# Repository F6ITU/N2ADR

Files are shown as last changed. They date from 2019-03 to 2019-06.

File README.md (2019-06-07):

# N2ADR
N2ADR HPF &amp;  lpf for the Hermes Lite V2 project (fork heavily modified) 

This fork of the original N2ADR filter project (https://github.com/softerhardware/Hermes-Lite2/tree/master/hardware/companions/n2adr )
is designed on less expansive 2 sides only PCB. This filter can be directly plugged on a Hermes Lite V2 board or installed as a "piggy back" extension
fixed over the HL2 main board. This way, all input/output of the transmission system are located on the main frontplate of the transceiver. 

  - TR/PTT I/O is now using the same stereo jack used on the HL2 board
  - RX only SMA plug has been added
  - "Low power TX" and "RX only" RF path are routed thru coaxial jumpers to avoid impedance mismatch 
  - A heavy stitching of the board compensates the lack of insulation between RF traces and command bus

A specific pcb frontpanel is under development to accomodate this new configuration. 

Caveat emptor : 

This fork is a prototype. If you don't like risks, please built the original design

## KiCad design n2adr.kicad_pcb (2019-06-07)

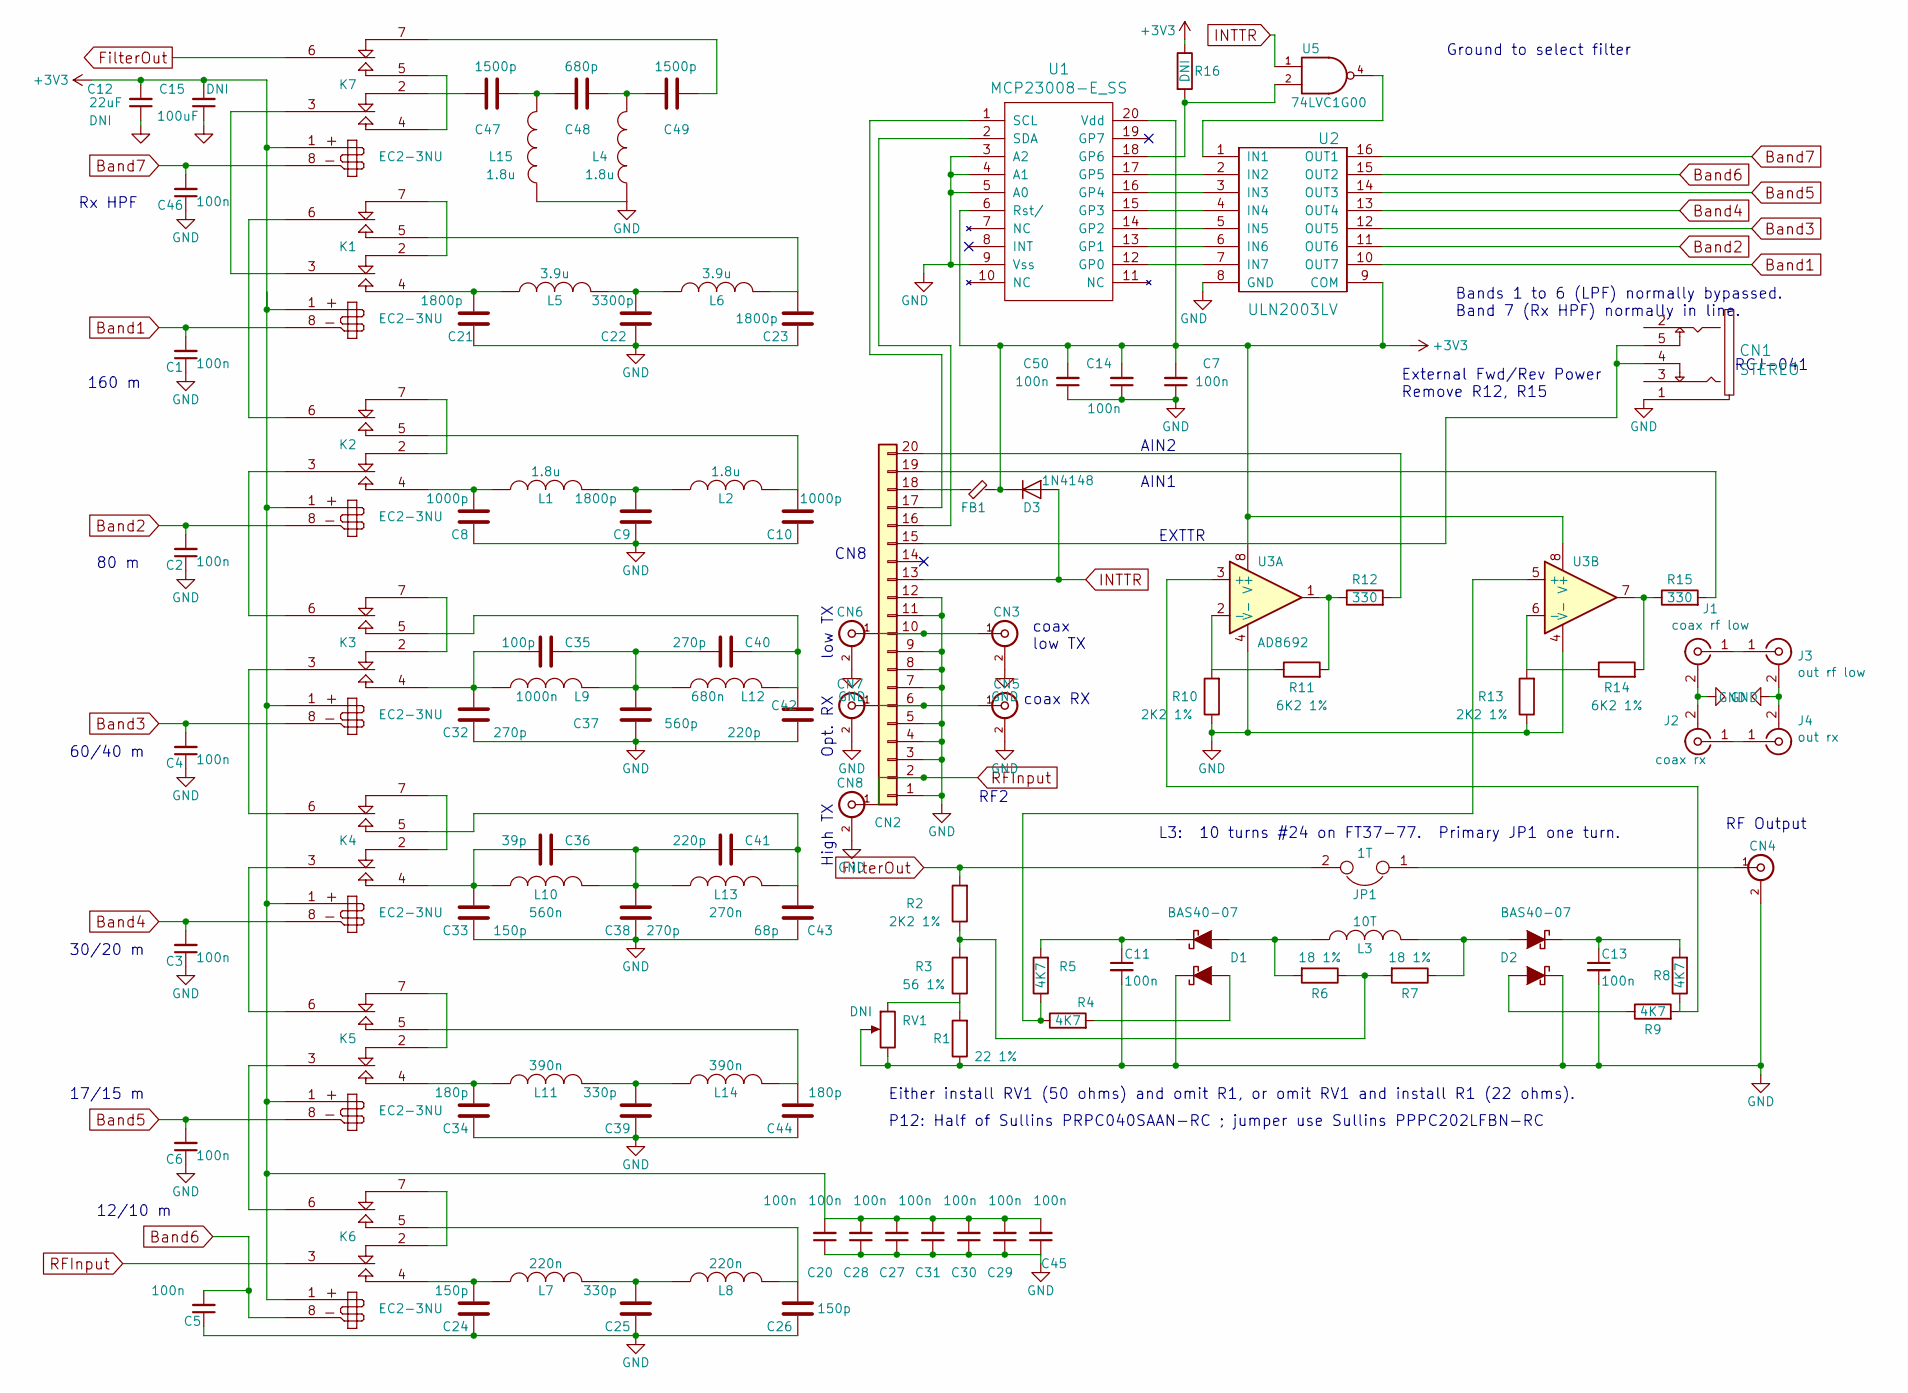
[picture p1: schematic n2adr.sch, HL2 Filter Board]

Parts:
C1, C2, C3, C4, C5, C6, C7, C11, C13, C14, C20, C27, C28, C29, C30, C31, C45, C46, C50: 100n; SMD_0805
C8, C10: 1000p; SMD_1206
C9, C21, C23: 1800p; SMD_1206
C12: 22uF; SMD_0805
C15: 100uF; SMD-1206
C22: 3300p; SMD_1206
C24, C26, C33: 150p; SMD_1206
C25, C39: 330p; SMD_1206
C32, C38, C40: 270p; SMD_1206
C34, C44: 180p; SMD_1206
C35: 100p; SMD_1206
C36: 39p; SMD_1206
C37: 560p; SMD_1206
C41, C42: 220p; SMD_1206
C43: 68p; SMD_1206
C47, C49: 1500p; SMD_0805
C48: 680p; SMD_0805
CN1: STEREO
CN2: Conn_01x20; Pin_Header_Straight_1x20_Pitch2.54mm
CN3: SMA; coax_2mm
CN4, CN6, CN7, CN8: SMA; SMA_EDGE_NRW
CN5: SMA; coax_1mm
D1, D2: BAS40-07; SOT-143
D3: 1N4148; D_SOD-123
FB1: FB; SMD_0805
J1: coax rf low; coax_2mm
J2: coax rx; coax_2mm
J3: out rf low; SMA_EDGE_NRW
J4: out rx; SMA_EDGE_NRW
JP1: 1T; WireConnection_1.20mmDrill
K1, K2, K3, K4, K5, K6, K7: EC2-3NU; RelayDPDT01
L1, L2: 1.8u; SMD_1812
L3: 10T; ToroidT37
L4, L15: 1.8u; SMD_0805
L5, L6: 3.9u; SMD_1812
L7, L8: 220n; SMD_1210
L9: 1000n; SMD_1812
L10: 560n; SMD_1210
L11, L14: 390n; SMD_1210
L12: 680n; SMD_1210
L13: 270n; SMD_1210
R1: 22 1%; SMD_0805
R2, R10, R13: 2K2 1%; SMD_0805
R3: 56 1%; SMD_0805
R4, R5, R8, R9: 4K7; SMD_0805
R6, R7: 18 1%; SMD_0805
R11, R14: 6K2 1%; SMD_0805
R12, R15: 330; SMD_0805
R16: DNI; SMD_0805
RV1: DNI; Trimpot_Bourns_3314G
U1: MCP23008-E_SS; SSOP-20_5.3x7.2mm_P0.65mm
U2: ULN2003LV; TSSOP-16_4.4x5mm_Pitch0.65mm
U3: AD8692; MSOP-8_3x3mm_Pitch0.65mm
U5: 74LVC1G00; SOT-23-5_HandSoldering

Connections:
+3V3: C7.2, C12.2, C14.2, C15.2, C20.2, C27.2, C28.2, C29.2, C30.2, C31.2, C45.2, C50.2, D3.1 (K), FB1.1, K1.1, K2.1, K3.1, K4.1, K5.1, K6.1, K7.1, R16.1, U1.6 (Rst/), U1.20 (Vdd), U2.9 (COM), U3.8 (V+), U5.5 (+3V3)
Band1: C1.2, K1.8, U2.10 (OUT7)
Band2: C2.2, K2.8, U2.11 (OUT6)
Band3: C4.2, K3.8, U2.12 (OUT5)
Band4: C3.2, K4.8, U2.13 (OUT4)
Band5: C6.2, K5.8, U2.14 (OUT3)
Band6: C5.2, K6.8, U2.15 (OUT2)
Band7: C46.2, K7.8, U2.16 (OUT1)
FilterOut: JP1.2, K7.6, R2.2
GND: C1.1, C2.1, C3.1, C4.1, C5.1, C6.1, C7.1, C8.1, C9.1, C10.1, C11.2, C12.1, C13.2, C14.1, C15.1, C20.1, C21.2, C22.2, C23.2, C24.1, C25.1, C26.1, C27.1, C28.1, C29.1, C30.1, C31.1, C32.1, C33.1, C34.1, C37.1, C38.1, C39.1, C42.1, C43.1, C44.1, C45.1, C46.1, C50.1, CN1.1, CN2.1, CN2.3, CN2.4, CN2.5, CN2.7, CN2.8, CN2.9, CN2.11, CN2.12, CN3.2 (Ext), CN4.2 (Ext), CN5.2 (Ext), CN6.2 (Ext), CN7.2 (Ext), CN8.2 (Ext), D1.1 (K), D2.2 (K), J1.2 (Ext), J2.2 (Ext), J3.2 (Ext), J4.2 (Ext), L4.1, L15.1, R1.1, R10.1, R13.1, RV1.2, RV1.3, U1.3 (A2), U1.4 (A1), U1.5 (A0), U1.9 (Vss), U2.8 (GND), U3.4 (V-), U5.3 (GND)
INTTR: CN2.13, D3.2 (A), U5.1
unnamed: C8.2, K2.4, L1.1
unnamed: C9.2, L1.2, L2.1
unnamed: C10.2, K2.5, L2.2
unnamed: C11.1, D1.2 (K), R5.2
unnamed: C13.1, D2.1 (K), R8.2
unnamed: C21.1, K1.4, L5.1
unnamed: C22.1, L5.2, L6.1
unnamed: C23.1, K1.5, L6.2
unnamed: C24.2, K6.4, L7.1
unnamed: C25.2, L7.2, L8.1
unnamed: C26.2, K6.5, L8.2
unnamed: C32.2, C35.2, K3.4, L9.1
unnamed: C33.2, C36.2, K4.4, L10.1
unnamed: C34.2, K5.4, L11.1
unnamed: C35.1, C37.2, C40.2, L9.2, L12.1
unnamed: C36.1, C38.2, C41.2, L10.2, L13.1
unnamed: C39.2, L11.2, L14.1
unnamed: C40.1, C42.2, K3.5, L12.2
unnamed: C41.1, C43.2, K4.5, L13.2
unnamed: C44.2, K5.5, L14.2
unnamed: C47.1, C48.2, L15.2
unnamed: C47.2, K7.2
unnamed: C48.1, C49.2, L4.2
unnamed: C49.1, K7.7
unnamed: CN1.4, CN1.5, CN2.15
unnamed: CN2.6, CN5.1 (In), CN7.1 (In)
unnamed: CN2.10, CN3.1 (In), CN6.1 (In)
unnamed: CN2.16, U1.2 (SDA)
unnamed: CN2.17, U1.1 (SCL)
unnamed: CN2.18, FB1.2
unnamed: CN2.19, R15.2
unnamed: CN2.20, R12.2
unnamed: CN4.1 (In), JP1.1
unnamed: D1.3 (A), L3.1, R6.2
unnamed: D1.4 (A), R4.2
unnamed: D2.3 (A), R9.1
unnamed: D2.4 (A), L3.2, R7.1
unnamed: J1.1 (In), J3.1 (In)
unnamed: J2.1 (In), J4.1 (In)
unnamed: K1.2, K1.7
unnamed: K1.3, K7.3
unnamed: K1.6, K2.6
unnamed: K2.2, K2.7
unnamed: K2.3, K3.6
unnamed: K3.2, K3.7
unnamed: K3.3, K4.6
unnamed: K4.2, K4.7
unnamed: K4.3, K5.6
unnamed: K5.2, K5.7
unnamed: K5.3, K6.6
unnamed: K6.2, K6.7
unnamed: K7.4, K7.5
unnamed: R1.2, R3.1, RV1.1
unnamed: R2.1, R3.2, R6.1, R7.2
unnamed: R4.1, R5.1, U3.5 (+)
unnamed: R8.1, R9.2, U3.3 (+)
unnamed: R10.2, R11.1, U3.2 (-)
unnamed: R11.2, R12.1, U3.1
unnamed: R13.2, R14.1, U3.6 (-)
unnamed: R14.2, R15.1, U3.7
unnamed: R16.2, U1.18 (GP6), U5.2
unnamed: U1.12 (GP0), U2.7 (IN7)
unnamed: U1.13 (GP1), U2.6 (IN6)
unnamed: U1.14 (GP2), U2.5 (IN5)
unnamed: U1.15 (GP3), U2.4 (IN4)
unnamed: U1.16 (GP4), U2.3 (IN3)
unnamed: U1.17 (GP5), U2.2 (IN2)
unnamed: U2.1 (IN1), U5.4
RFInput: CN2.2, CN8.1 (In), K6.3

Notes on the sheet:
Ground to select filter
RF Output
L3: 10 turns #24 on FT37-77. Primary JP1 one turn.
80 m
60/40 m
30/20 m
17/15 m
12/10 m
160 m
RF2
EXTTR
AIN2
AIN1
CN8
Opt. RX
External Fwd/Rev Power Remove R12, R15
RCJ-041
P12: Half of Sullins PRPC040SAAN-RC ; jumper use Sullins PPPC202LFBN-RC
Either install RV1 (50 ohms) and omit R1, or omit RV1 and install R1 (22 ohms).
Rx HPF
Bands 1 to 6 (LPF) normally bypassed. Band 7 (Rx HPF) normally in line.
coax low TX
coax RX
low TX
High TX

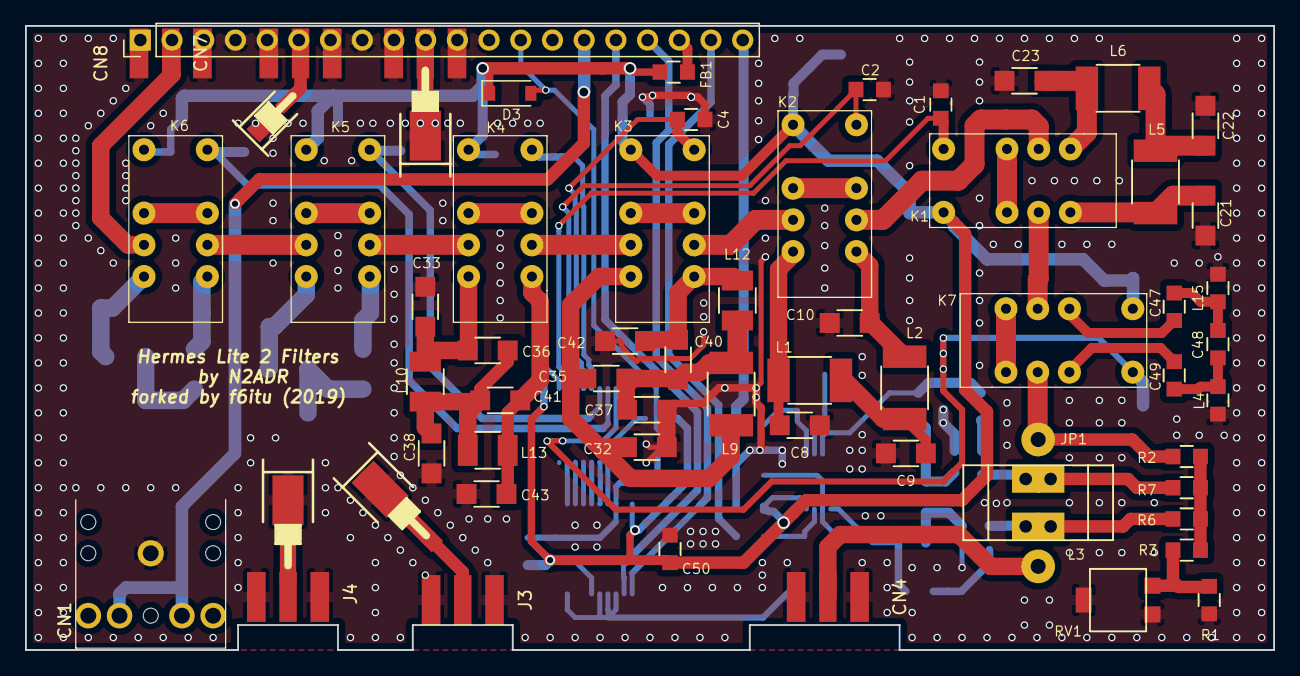
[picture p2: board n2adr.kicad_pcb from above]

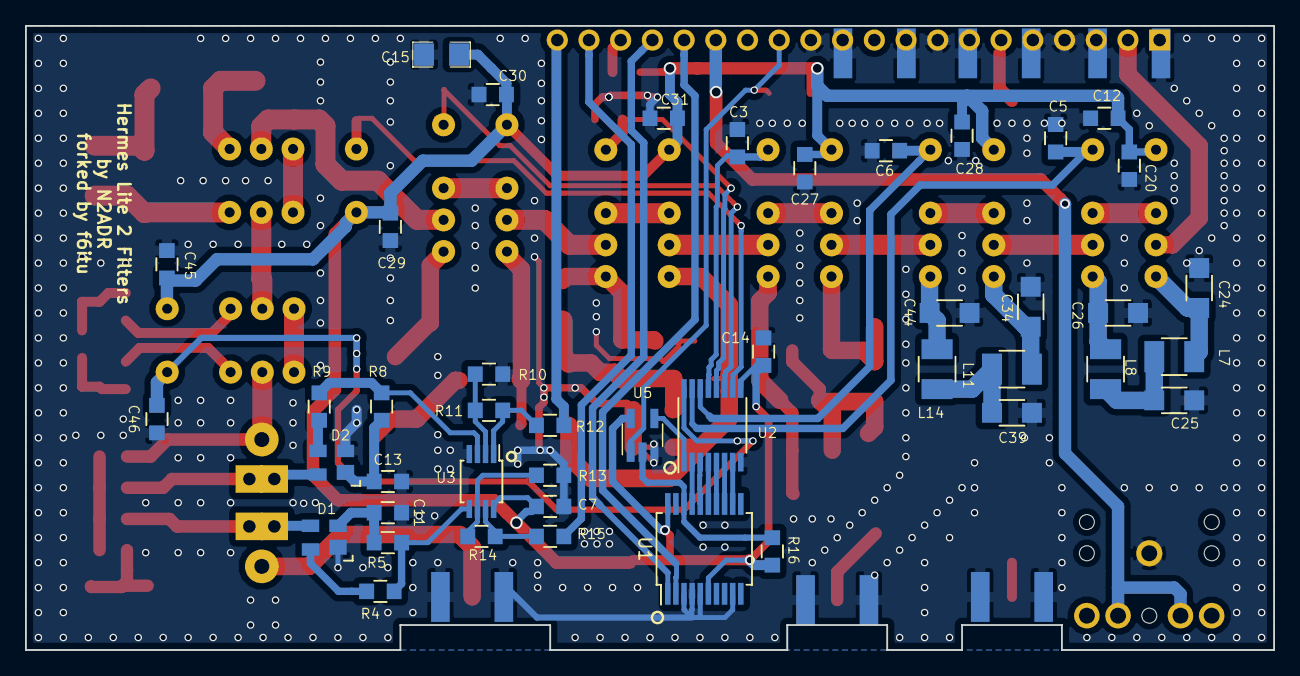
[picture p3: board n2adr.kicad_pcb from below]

Board: 4 copper layers, 100.0 x 50.0 mm, 106 parts (44 on the bottom side), 80 nets.

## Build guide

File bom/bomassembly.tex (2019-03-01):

\documentclass{article} 
\usepackage[english]{babel}
\usepackage[bookmarks=false]{hyperref}
\usepackage{pdflscape}
\usepackage{xcolor}
\usepackage{longtable}
\usepackage[T1]{fontenc}
\hypersetup{
    colorlinks,
    linkcolor={red!50!black},
    citecolor={blue!50!black},
    urlcolor={blue!80!black}
}
\usepackage[letterpaper, landscape, left=1.3cm, right=1.3cm, top=2cm, bottom=2.5cm]{geometry}

\begin{document}

\input{bompre.dat}

\begin{center}
    \begin{longtable}{| r | p{6.0cm} | p{3.8cm} | l | p{3.8cm} | l | r | r |}
    \hline
	\multicolumn{1}{|l|}{\textbf{Line}} & \multicolumn{1}{l|}{\textbf{Description}} & \multicolumn{1}{l|}{\textbf{Part Number}} & \multicolumn{1}{l|}{\textbf{Sub OK}} & \multicolumn{1}{l|}{\textbf{Designators}} & \multicolumn{1}{l|}{\textbf{Footprint}} & \multicolumn{1}{r|}{\textbf{Pins}} & \multicolumn{1}{r|}{\textbf{Quantity}} \\ \hline	 
	\endhead
	\input{bom.dat}
    \end{longtable}
\end{center}

\input{bompost.dat}

\end{document}

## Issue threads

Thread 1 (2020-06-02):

3.5mm jack is reversed

f4grx, 2020-06-02:
The 3.5mm jack footprint has an incorrect rotation. It cannot be soldered in.

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

Project files and gerbers should be updated for next batch.

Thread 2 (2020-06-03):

Bent coax wire are hard to use with stiff wires

f4grx, 2020-06-03:
It's hard to solder a stiff coax wire between the endpoints. TODO make them straight.

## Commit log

2019-03-01 first design, initial commit
    [n2adr.kicad_pcb, n2adr.sch]
2019-03-15 upgrade to Kicad 5.x, 2 layers less
    [n2adr.kicad_pcb, n2adr.sch]
2019-06-07 minor pcb changes still under dev
    [n2adr-B.Cu.gbr, n2adr-B.Mask.gbr, n2adr-B.Paste.gbr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]
